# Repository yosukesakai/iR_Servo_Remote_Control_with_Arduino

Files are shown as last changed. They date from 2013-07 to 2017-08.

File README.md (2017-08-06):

# iR Servo Remote Control with Arduino

### Project Outline

#### Background
[山口情報芸術センター](http://www.ycam.jp)YCAMの館内には、ホワイエとよばれる広場があります。ここでは様々な作品展示やイベントが行われます。ホワイエを照らす備え付けの照明はありません。3階にあるテラスに設置した仮設の照明をいつも用いています。  
仮設照明は舞台用の照明で、on/offは照明の近くにおかれたスイッチボックスで行います。この操作は手動で行わなければなりません。このため、毎朝毎晩、このスイッチを操作するために、1階にいるスタッフが、3階まで(しかも奥まった場所!)5分以上かけて往復しなければなりませんでした(しまも2カ所!)。  
この照明を1階から遠隔操作できるようにしよう、というのがこのプロジェクトの目的です。    

YCAM has a large space called "Foyer". Various exhibition and events are held there. I does not have lights that are permanently-installed. It has only temporary-installed lights on 3rd floor.  
temporary-installed lights are for stage and controlled by switch box that is installed close to the lights. It is operated manually. So a staff has to goto 3rd floor (even it is at deep-set! ) from 1st floor in every morning and night to oparate it. It takes more than 5 min!  
So I decided to make something to controll the lights from 1st floor.  

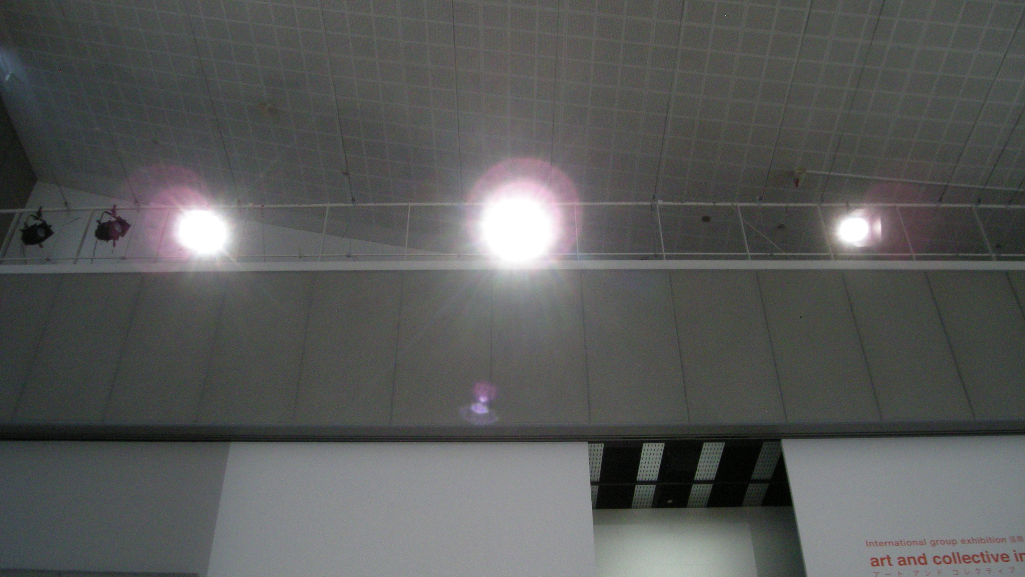
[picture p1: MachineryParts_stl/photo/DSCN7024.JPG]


#### Goal

This project aims to make a system to controll a toggle switch remotely. A User send iR signal with iR remote controller (Panasonic) to Arduino with iR receiver module, then the Arduino moves servo moter to turn on/off a toggle switch. 

スイッチボックスに納められたトグルスイッチを遠隔操作するシステムを制作する。赤外線リモコン(Panasonic)から発信した赤外線をArduinoに接続した赤外線受信モジュールで受信し、信号に応じて、トグルスイッチに接続したサーボモータを動かす。

```
Relay controll system is suitable for this kind of solution nomally, 
but cause of some reason, I took this method.
この課題に対して、普通はリレーを制御するシステムを制作するだろうが、もろもろの事情によりこの方式となった。
```
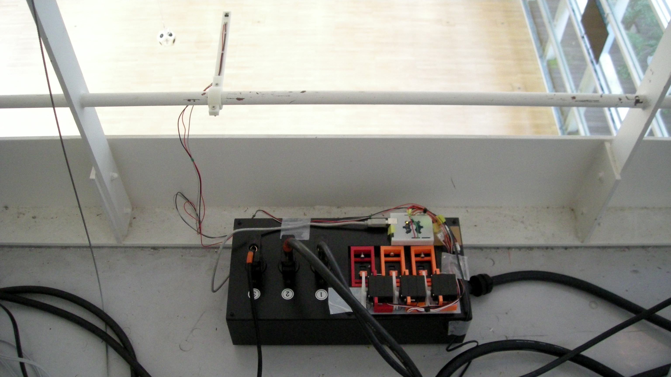
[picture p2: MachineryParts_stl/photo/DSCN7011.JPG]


## Instruction

## Hardware

### Servo Motor

Connect servo motor (GWS Servo S03T/2BBMG/F) to Arduino Uno  

(Servo1)
1.servo motor's Grand to Arduino's Ground  
2.servo motor's PWR to Arduino's +5V  
3.servo motor's signal to Arduino's #9

(Servo2)
1.servo motor's Grand to Arduino's Ground  
2.servo motor's PWR to Arduino's +5V  
3.servo motor's signal to Arduino's #10

(Servo3)
1.servo motor's Grand to Arduino's Ground  
2.servo motor's PWR to Arduino's +5V  
3.servo motor's signal to Arduino's #11

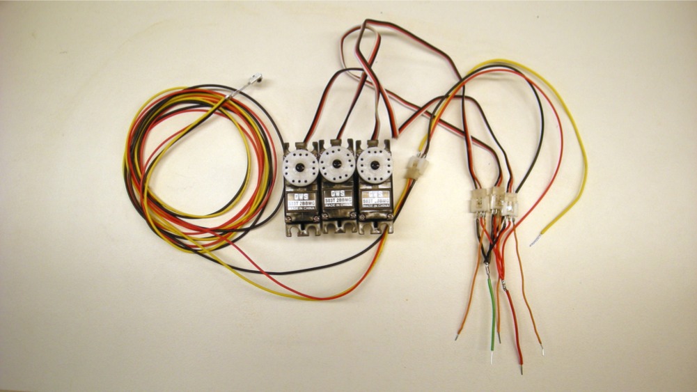
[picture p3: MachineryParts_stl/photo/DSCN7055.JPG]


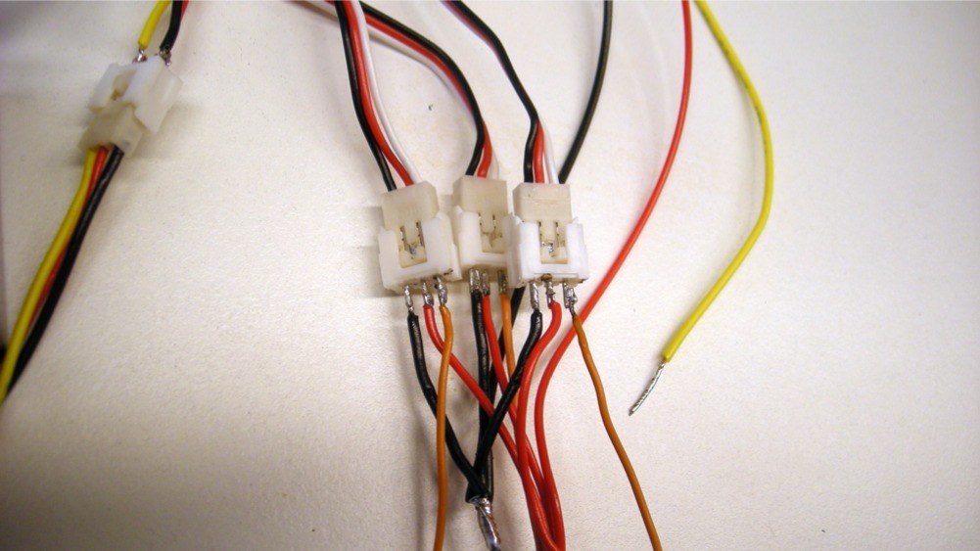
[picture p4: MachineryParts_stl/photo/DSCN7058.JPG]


### iR Receiver Module

Connect iR Receiver Module (PL-IRM0101(38kHz)with shield) to Arduino  

1.iR Receiver's Grand to Arduino's Ground  
2.iR Receiver's PWR to Arduino's +5V  
3.iR Receiver's signal to Arduino's #2  

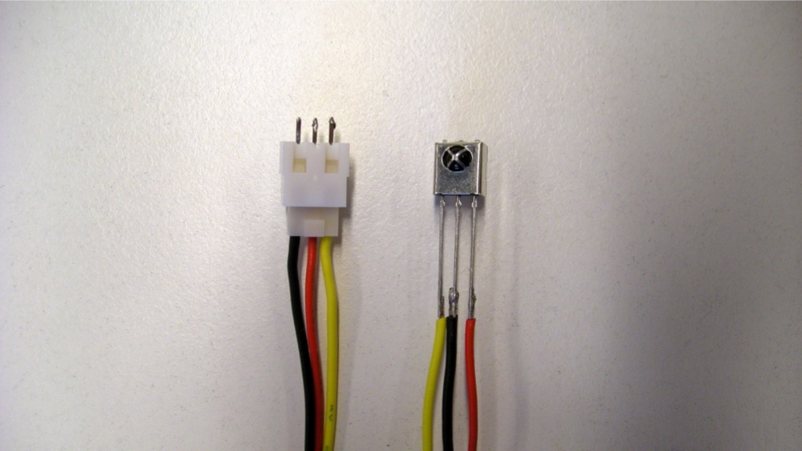
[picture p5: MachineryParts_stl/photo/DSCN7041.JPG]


and give power to arduino

## Software

### Analyse and Set Signal

Analyze signal code of your remote controller
with the code shown below  

(Panasonic projector's remote controller works well with this code. But Sony's does not.)  

```
赤外線通信の実験２  
http://www.geocities.jp/zattouka/GarageHouse/micon/InfraredCOM/InfraredCOM2.htm
```

And set the signal code that you want to use for control the servo motor  
in proper place in the code "iR_Servo_RemoteControl.ino"

then you can controll servo motor with your iR remote controller  

### Send Code to Arduino

Send the Code to Arduino  

## Machinery

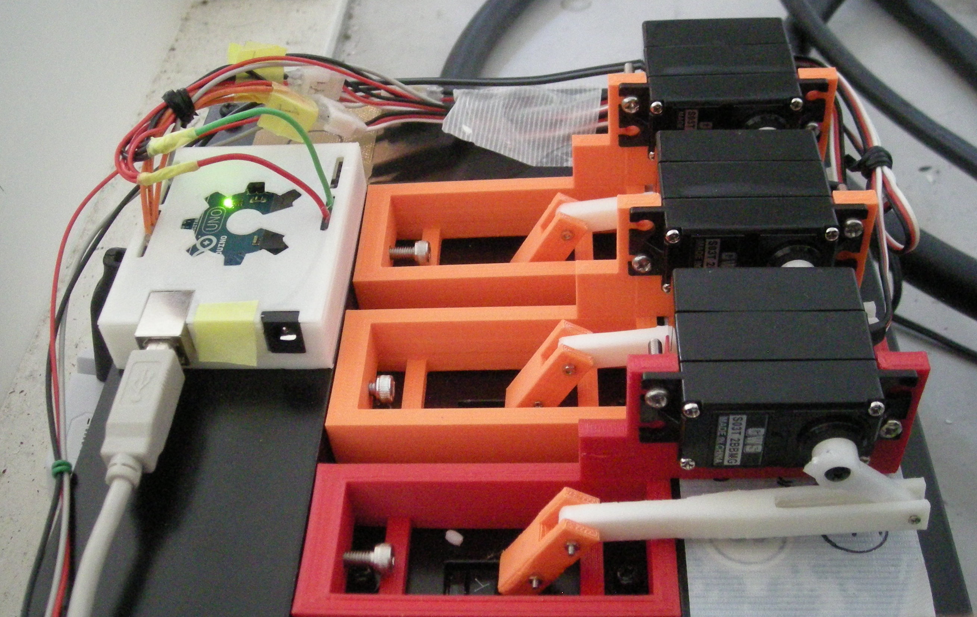
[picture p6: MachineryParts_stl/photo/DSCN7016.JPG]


### Print Parts

Print Parts:  
Basement  
Lever  
NobExtender  
SensorSupport_Upper
SensorSupport_lower

### Install Parts
  
Install parts with proper screw (M1.7, M3, M4)  

# Reference

### Source Code
Source code is published on github described below.  
ソースコード(Arduino用)はgithubに保存/公開している。  
https://github.com/yosukesakai/iR_Servo_Remote_Control_with_Arduino  

```
This is for break down test.
こちらは下記耐久試験用。
iR_Servo_RemoteControl_for_test.ino
```  

#### Reference for code  
コード作成にあたっては以下のウェブサイトを参照した。  
  
Servo library  
http://arduino.cc/en/reference/servo

赤外線通信の実験２  
http://www.geocities.jp/zattouka/GarageHouse/micon/InfraredCOM/InfraredCOM2.htm

### Parts

Mount for servo moter, Lever, Extender for switch nob.  
サーボモータのマウント、サーボモータとトグルスイッチをつなぐ為のリンク(レバーとのノブエクステンダー)を作成

#### Prototyping
Tried some patterns for layout of servo motor mount and lever avoiding hitting ohter perts.  
Made break down test turning on/off 1000times.  

マウントレイアウト、周辺部材に接触しないレバーの逃がし等について、複数の試作を行った。  
プロトタイプ完成後、耐久試験(on/off:1000回)を行い、問題がないことを確認した。(経年劣化については無視することとした。加水分解に対する耐久性の検討など、今後の課題とする。)  

#### Printing  
Printed with Makerbot Replicator2X. Set parameters below to secure proper strength.  
Makerbot Replicator2Xにて出力した。強度を確保する為、maker wareにて以下のパラメータを設定した。  
  
```
infill: 50%  
number of shells: 3  
```

stl file is also published on thingiverse.  
完成したstlファイルはThingiverseでも保存/公開している。
  
iR Servo Remote Control with Arduino    
http://www.thingiverse.com/thing:103600

### Electric Parts

Controller: Arduino UNO  
Servo Motor: GWS Servo S03T/2BBMG/F (relatively high torque)   
iR remote controller reciever module: PL-IRM0101(38kHz)with shield  

### iR Data from Remote Controller

#### Panasonic Projector Remote Controller

if slide switch = Computer Numetric  
  
1:10  
2:11  
3:12  
4:13  
5:14  
6:15  
7:16  
8:17  
9:18  
0:19  
next:F  
aspect:DE  
light:no emittion(out of order?)  
id all:6B  
is set:6C  
  
AUTO SETUP:1  
ON?:3E  
OFF?:3F  
RBG1:A  
RGB2:B  
VIDEO:3  
S-VIDEO:no emittion(out of order?)  
SHUT:91  
MENU:7A  
FREEZE:2  

if slide switch = Projector  

1:3B  
2:62  
3:70  
4:9  
5:5  
6:4  
7:7C  
8:35  
9:36  
0:81  
next:F  
aspect:DE  
light:no emittion(out of order?)  
id all:6B  
is set:6C  

## Licenses and Credits  

<br /> 
<span xmlns:dct="http://purl.org/dc/terms/" href="http://purl.org/dc/dcmitype/Text" property="dct:title" rel="dct:type">iR_Servo_Remote_Control_with_Arduino</span><a xmlns:cc="http://creativecommons.org/ns#" href="https://github.com/yosukesakai/iR_Servo_Remote_Control_with_Arduino" property="cc:attributionName" rel="cc:attributionURL">  
Produced by yosukesakai<br /></a>
iR_Servo_Remote_Control_with_Arduino (documentation, photo, stl file except codes) is licensed under a <a rel="license" href="http://creativecommons.org/licenses/by-sa/3.0/">Creative Commons Attribution - ShareAlike 3.0 Unported License.<br />

Source code of this project shoud be published under open source license. But some part is quotation from other's code that is not published under open source license. So currently, the source code on this website cannot be published under open source license. Usage of the code in accordance with the law is welcome :)

##Disclaimer
```
yosukesakai makes no guarantees whatsoever related to this text.
The persons involved in the creation/operation of this website (including other users) take no responsibility regarding 
the usage of this text (including any kind of use such as browsing, contribution, or external re-use; 
the same shall apply hereinafter).
When using this text, you are required to take personal responsibility. 
yosukesakai takes no responsibility regarding eventual damage resulting from your use of this text.
yosukesakai does not guarantee that your use of this text is legitimate according to applicable laws.
We don't guarantee in any way the legitimacy, accuracy and safety of all information provided as contents.
We make no guarantees regarding external website linked to from this site.
This text permits alteration or reuse based on the Creative Commons Attribution-ShareAlike 3.0 Unported License, 
however it does not permit forms of reuse that violate laws or other regulations.  
The use of images accompanying the text may be based on license agreements separate from the respective text licenses.  
yosukesakai may discontinue the publication of all or parts of this text and all other contents without prior notice.
```

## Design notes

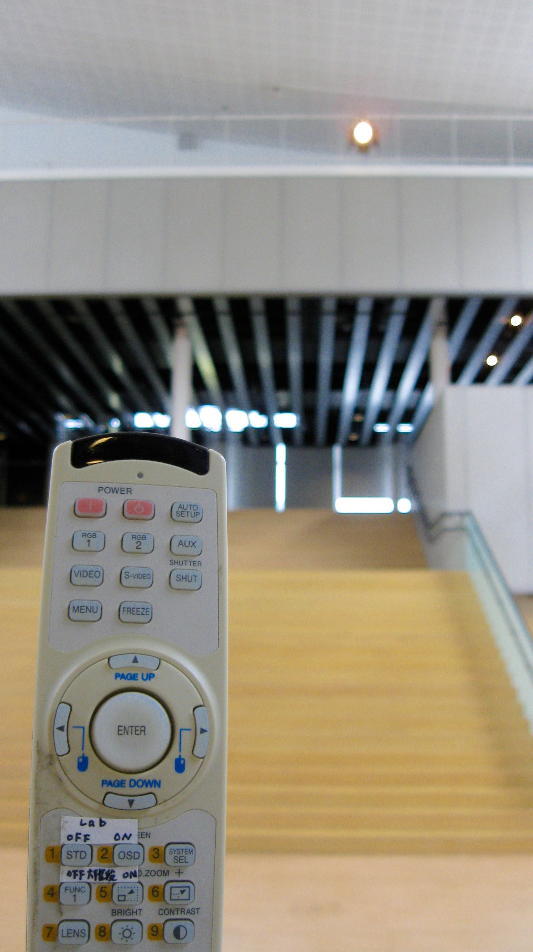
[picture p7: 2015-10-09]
image/i - 1.jpg

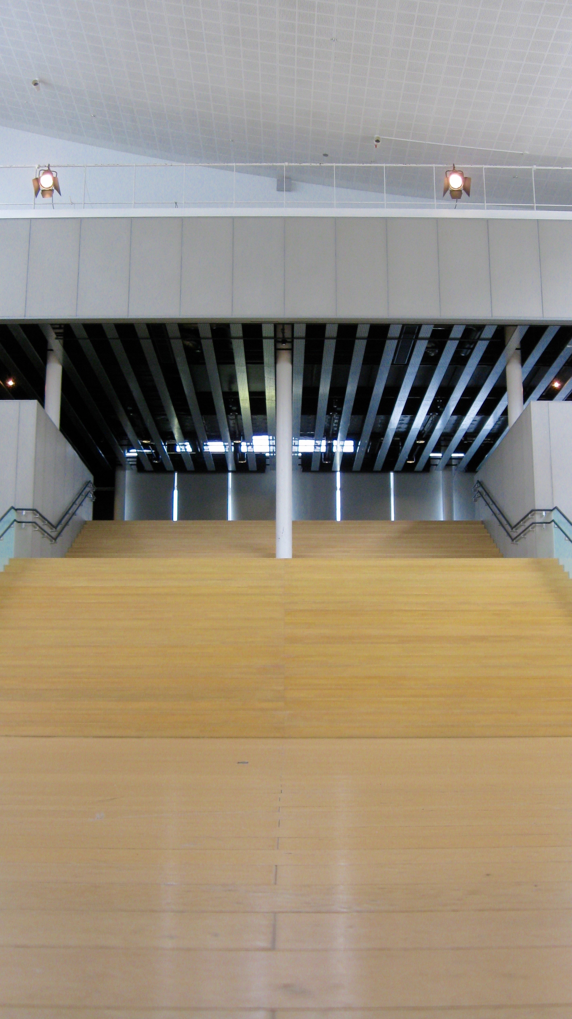
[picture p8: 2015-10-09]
image/i - 2.jpg

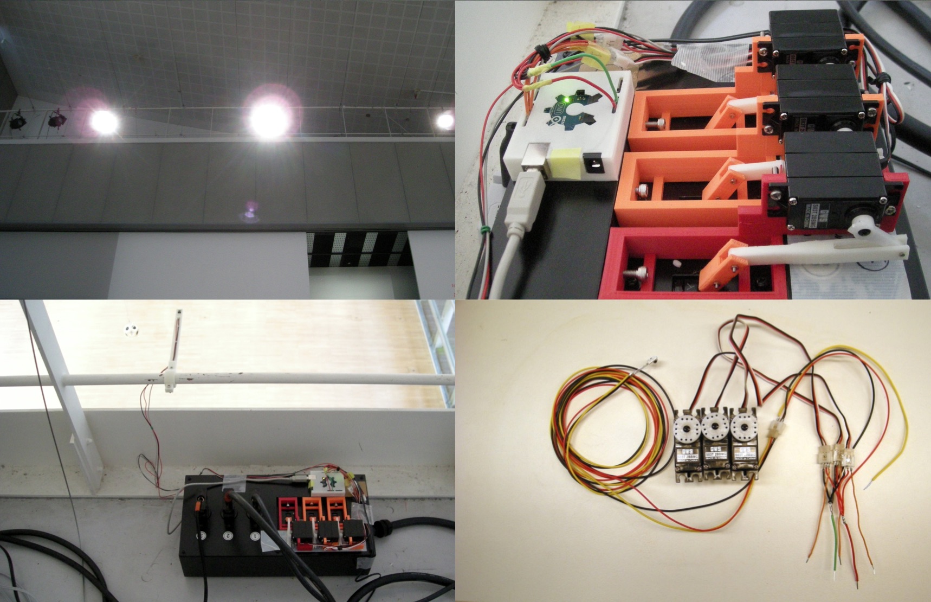
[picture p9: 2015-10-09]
image/iR_Servo_Remote Control_with_Arduino.jpg

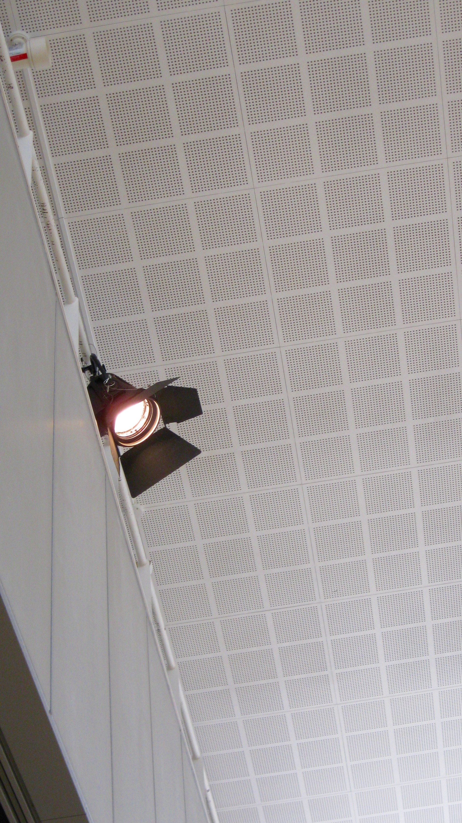
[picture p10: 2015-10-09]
image/i - 3.jpg

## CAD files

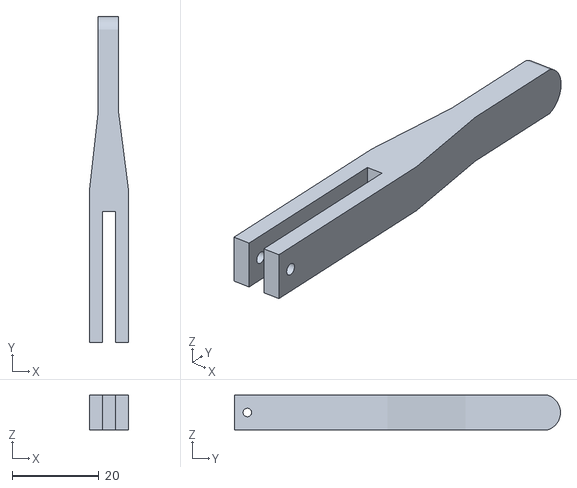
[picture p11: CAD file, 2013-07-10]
MachineryParts_stl/(IRSERVO)Lever.stl
9.00 x 75.3 x 8.00

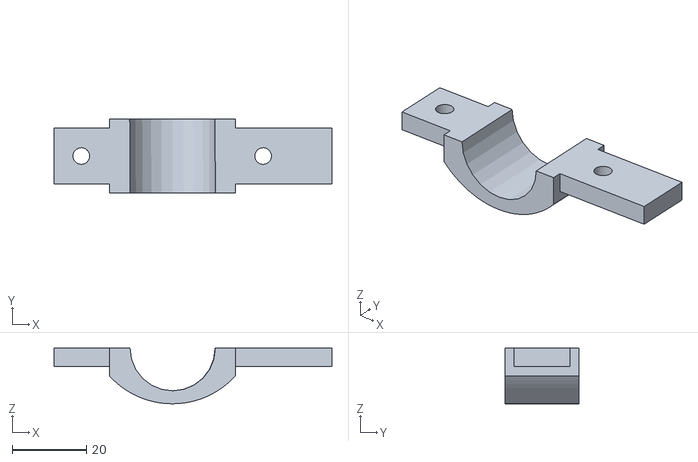
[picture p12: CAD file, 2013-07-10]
MachineryParts_stl/(IRSERVO)SensorSupport_Upper.stl
75.0 x 20.0 x 15.0

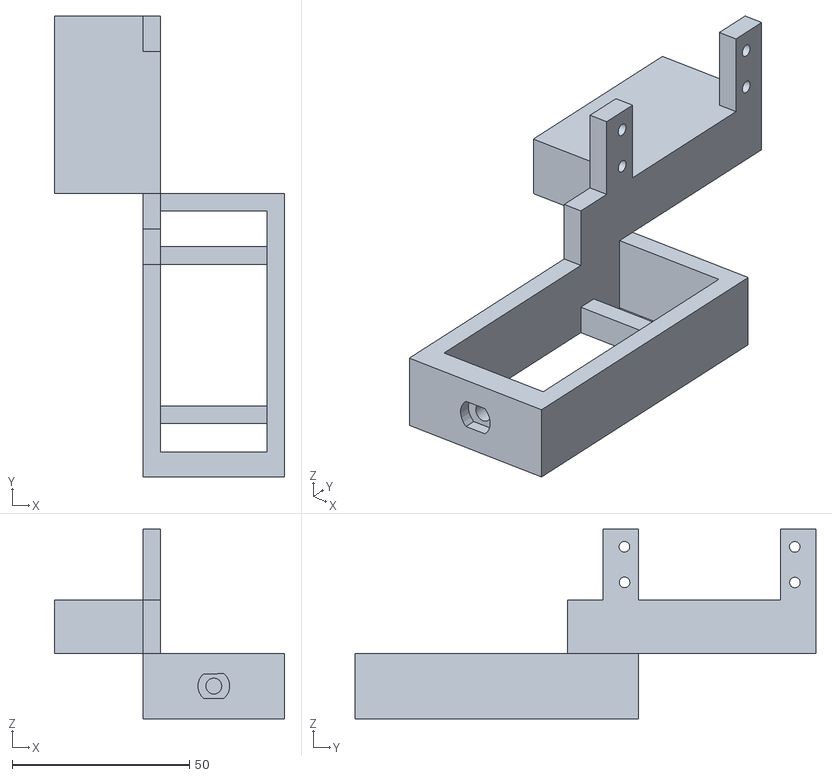
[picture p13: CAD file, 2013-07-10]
MachineryParts_stl/(IRSERVO)BASEMENT.stl
65.0 x 130.0 x 53.5

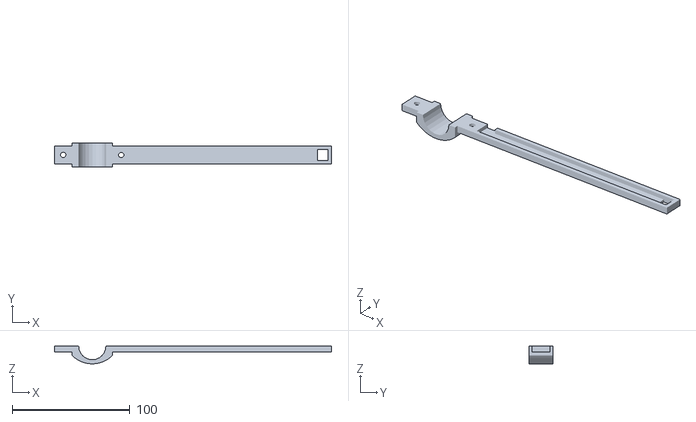
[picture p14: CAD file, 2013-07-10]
MachineryParts_stl/(IRSERVO)SensorSupport_Lower.stl
235.0 x 20.0 x 15.0

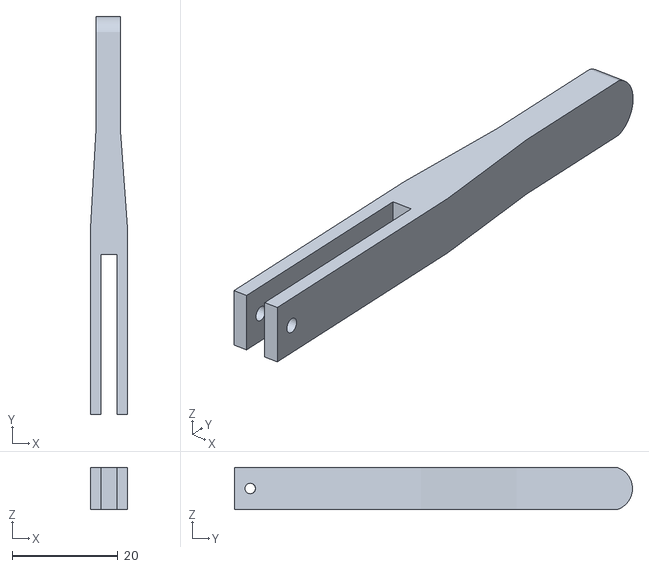
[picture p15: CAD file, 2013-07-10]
MachineryParts_stl/(IRSERVO)Lever(Narrow).stl
7.00 x 75.3 x 8.00

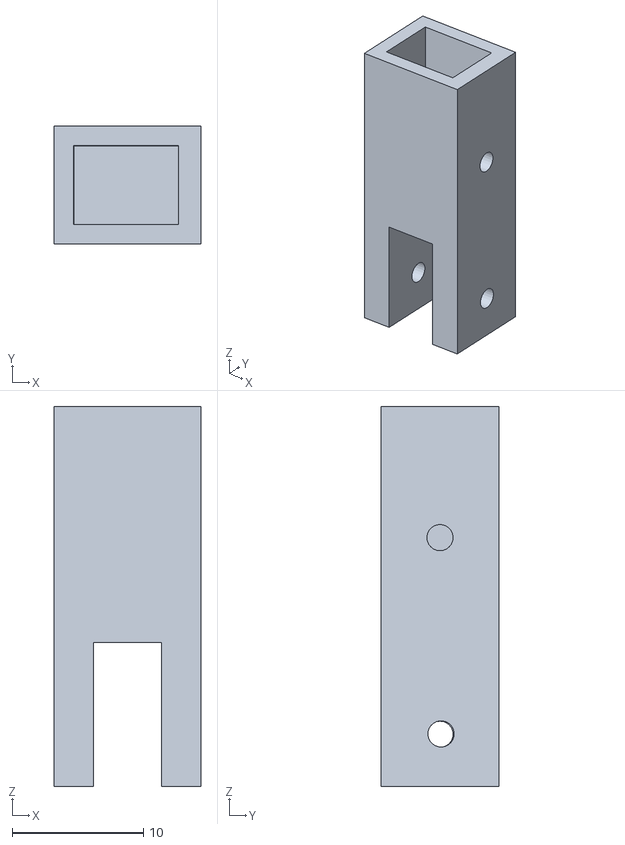
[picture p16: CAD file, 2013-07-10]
MachineryParts_stl/(IRSERVO)NobExtender.stl
11.2 x 9.00 x 29.0

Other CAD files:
MachineryParts_stl/iRServoRemoteControl.skp

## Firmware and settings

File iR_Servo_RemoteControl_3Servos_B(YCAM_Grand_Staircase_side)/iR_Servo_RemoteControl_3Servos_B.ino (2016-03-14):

#define IR_PIN      2		// Pin# for iR Receiver Signal line 赤外線受信モジュール接続ピン番号
#define DATA_POINT  6           // Data Point of Received iR Data 受信したデータから読取る内容のデータ位置 Panasonic Projector Remote Controller >> 6
#include <Servo.h>              // Library for Servo 

Servo myservo_1;                  // set up for servo_1
Servo myservo_2;                  // set up for servo_2
Servo myservo_3;                  // set up for servo_3

/*
how to set servo position
    myservo_1.write(1);           // set servo 1 position 1 degree            
    delay(28000);                       
    myservo_1.write(179);         // set servo 1 position 179 degree   
    delay(28000);
*/


// 初期化処理
void setup()
{
  
     Serial.begin(9600) ;	// ready for sirial communication パソコン(ArduinoIDE)とシリアル通信の準備を行う
     pinMode(IR_PIN,INPUT) ;	// set IR_PIN as Digital Input 赤外線受信モジュールに接続ピンをデジタル入力に設定
     
     myservo_1.attach( 9 );       // servo 1 controll line > digital 9
     myservo_1.write(0);               // set initial position of servo

     myservo_2.attach( 10 );       // servo 2 controll line > digital 10
     myservo_2.write(0);               // set initial position of servo
     
     myservo_3.attach( 11 );       // servo 3 controll line > digital 11
     myservo_3.write(0);               // set initial position of servo

       
}






// メインの処理
void loop()
{
  
     int ans ;
     ans = IRrecive() ;                      // Receive iR Data 赤外線リモコンのデータを受信する


     if (ans != 0) Serial.println(ans,HEX) ; // Display Received Data リモコンからデータを受信したら表示する


     if (ans != 0) {
          switch(ans) {
            
           case 0x13:     myservo_1.write(00);          // get signal 10 (button "4" ) then set servo position ** degree  //0x13 means button "4"
                          delay( 500 );   
                          
                          myservo_2.write(00);          // get signal 10 (button "4" ) then set servo position ** degree 
                          delay( 500 ); 

                          myservo_3.write(00);          // get signal 10 (button "4" ) then set servo position ** degree                   
                          delay( 200 );     
                          
                   break ;
                   
                   
           case 0x14:     myservo_1.write(100);         // get signal 11 (button "5" ) then set servo position ** degree  //0x14 means button "5"
                          delay( 500 );   
                          
                          myservo_2.write(83);         // get signal 11 (button "5" ) then set servo position ** degree 
                          delay( 500 ); 

                          myservo_3.write(90);         // get signal 11 (button "5" ) then set servo position ** degree                   
                          delay( 200 ); 
                   
                   break ;
                   
                   
           case 0xd7: 
                   break ;
           case 0x57: 
                   break ;

          }
     }
}







// 赤外線リモコンのデータを受信する処理関数
int IRrecive()
{
     unsigned long t ;
     int i , j ;
     int cnt , ans ;
     char IRbit[64] ;

     ans = 0 ;
     t = 0 ;
     if (digitalRead(IR_PIN) == LOW) {
          // リーダ部のチェックを行う
          t = micros() ;                          // 現在の時刻(us)を得る
          while (digitalRead(IR_PIN) == LOW) ;	// HIGH(ON)になるまで待つ
          t = micros() - t ;					// LOW(OFF)の部分をはかる
     }
     // リーダ部有りなら処理する(3.4ms以上のLOWにて判断する)
     if (t >= 3400) {
          i = 0 ;
          while(digitalRead(IR_PIN) == HIGH) ;	// ここまでがリーダ部(ON部分)読み飛ばす
          // データ部の読み込み
          while (1) {
               while(digitalRead(IR_PIN) == LOW) ;// OFF部分は読み飛ばす
               t = micros() ;
               cnt = 0 ;
               while(digitalRead(IR_PIN) == HIGH) {// LOW(OFF)になるまで待つ
                    delayMicroseconds(10) ;
                    cnt++ ;
                    if (cnt >= 1200) break ;		// 12ms以上HIGHのままなら中断
               }
               t = micros() - t ;
               if (t >= 10000) break ;			// ストップデータ
               if (t >= 1000)  IRbit[i] = (char)0x31 ;	// ON部分が長い
               else            IRbit[i] = (char)0x30 ;	// ON部分が短い
               i++ ;
          }
          // データ有りなら指定位置のデータを取り出す
          if (i != 0) {
               i = (DATA_POINT-1) * 8 ;
               for (j=0 ; j < 8 ; j++) {
                    if (IRbit[i+j] == 0x31) bitSet(ans,j) ;
               }
          }
     }
     return( ans ) ;
}


/*

iR Data from Remote Controller

Panasonic Projector Remote Controller

if slide switch = Computer Numetric

1:10 2:11 3:12 4:13 5:14 6:15 7:16 8:17 9:18 0:19 next:F aspect:DE light:no emittion(out of order?) id all:6B is set:6C

AUTO SETUP:1 ON?:3E OFF?:3F RBG1:A RGB2:B VIDEO:3 S-VIDEO:no emittion(out of order?) SHUT:91 MENU:7A FREEZE:2

if slide switch = Projector

1:3B 2:62 3:70 4:9 5:5 6:4 7:7C 8:35 9:36 0:81 next:F aspect:DE light:no emittion(out of order?) id all:6B is set:6C

*/

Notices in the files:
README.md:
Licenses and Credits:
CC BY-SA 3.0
